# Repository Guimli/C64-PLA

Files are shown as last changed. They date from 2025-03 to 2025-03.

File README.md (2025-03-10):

# Another C64 PLA

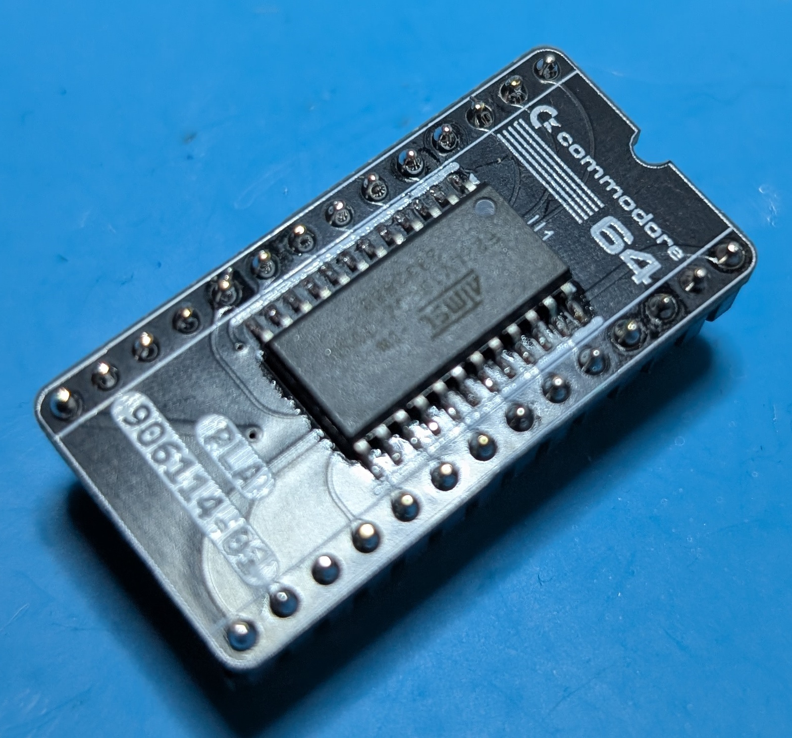
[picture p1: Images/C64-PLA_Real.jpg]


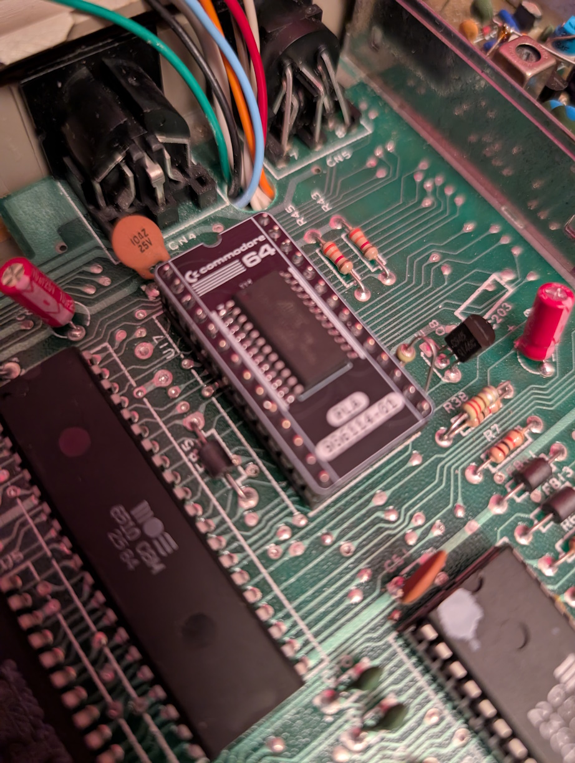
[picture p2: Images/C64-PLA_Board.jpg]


And yes... Another PLA for the C64. There are already too many available. But I thought they were all too big and ugly.
This version uses SOIC format components. This reduces the size of the PCB to that of a standard DIP28. And the components used are still produced, and can therefore be bought from a supplier.
To design this PLA, I used Lubomir Rintel's excellent work: https://github.com/lkundrak/yac64pla

Approximate cost for one C64-PLA (costs can reduced if you build several modules) :

(Be careful to select ATF22LV10s with an access time of 30ns. The Commodore 64 does not appreciate components that are too fast...)

- 2 x ATF22LV10CQZ-30SU  : 8.16 €
- PCB (with Shipping cost) : 23 €
- 2 x 14 pin P2.54 : 4.36 €

Total : 35.52 €

I can sell you this module if you don't want to assemble it yourself. Contact me on guimli@free.fr

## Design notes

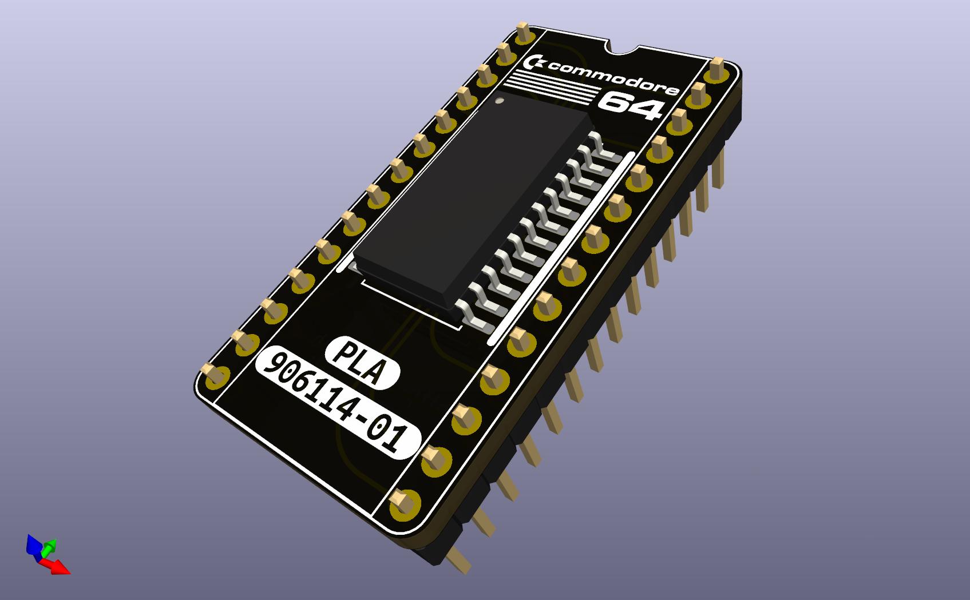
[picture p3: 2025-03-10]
Images/3D.jpg

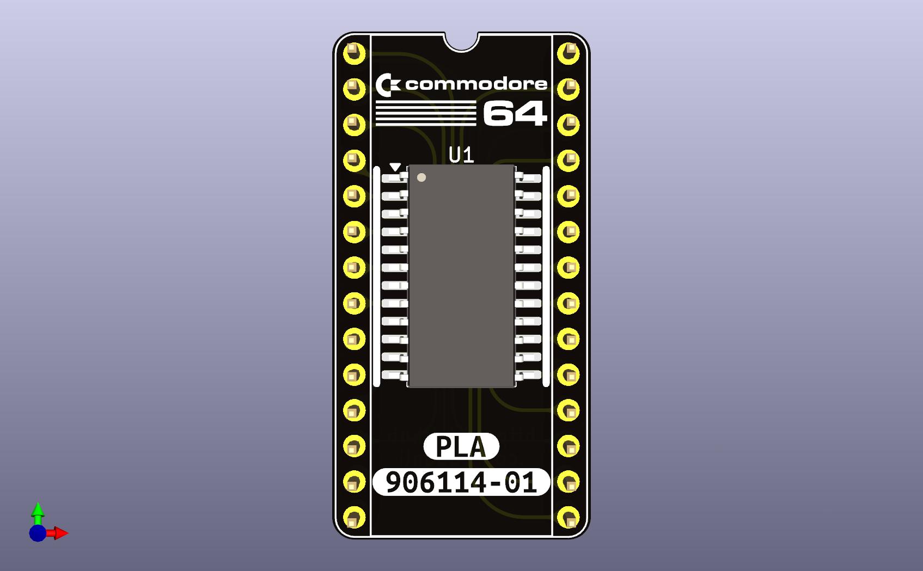
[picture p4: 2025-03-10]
Images/Top.jpg

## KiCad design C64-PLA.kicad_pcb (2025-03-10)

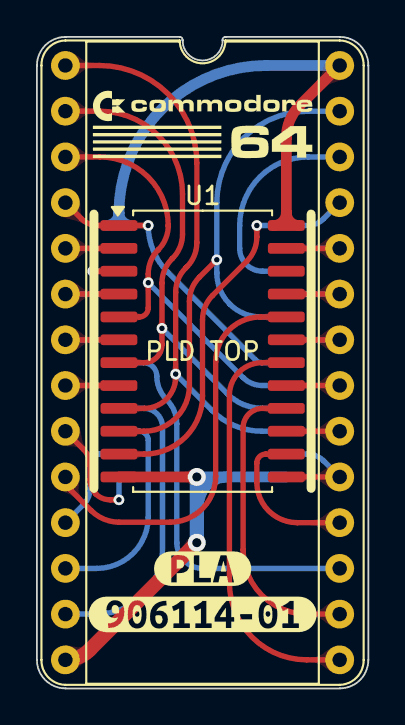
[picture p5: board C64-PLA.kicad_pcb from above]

Board: 2 copper layers, 18.4 x 36.2 mm, 5 parts (1 on the bottom side), 29 nets.

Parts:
U1, U2: ATF22V10C; SOIC-24W_7.5x15.4mm_P1.27mm
U3: C64_PLA; DIP-28_W15.24mm_Socket
kibuzzard-6781C1DF: G***; kibuzzard-6781C1DF
kibuzzard-6781C1F4: G***; kibuzzard-6781C1F4

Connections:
/A12: U1.10 (I9), U2.5 (I4), U3.27 (I8/A12)
/A13: U1.7 (I6), U2.9 (I8), U3.2 (I7/A13)
/A14: U1.5 (I4), U2.8 (I7), U3.3 (I6/A14)
/A15: U1.1 (I0/CLK), U2.7 (I6), U3.4 (I5/A15)
/BA: U2.3 (I2), U3.26 (I9/BA)
/FE: U1.9 (I8), U2.10 (I9), U3.1 (FE/NC)
/GR/~W: U2.16 (I/O14), U3.13 (F4/GR/~W)
/R/~W: U1.23 (I/O21), U2.2 (I1), U3.24 (I11/R/~W)
/TCR: U1.3 (I2), U2.22 (I/O20)
/VA12: U1.15 (I/O13), U3.20 (I15/VA12)
/VA13: U1.17 (I/O15), U3.21 (I14/VA13)
/~AEC: U1.11 (I10), U2.1 (I0/CLK), U3.25 (I10/~AEC)
/~BASIC: U2.18 (I/O16), U3.17 (F1/~BASIC)
/~CASRAM: U1.14 (I/O12), U3.18 (F0/~CASRAM)
/~CAS: U2.13 (I11), U3.9 (I0/~CAS)
/~CHAREN: U1.4 (I3/PD), U2.21 (I/O19), U3.6 (I3/~CHAREN)
/~CHAROM: U1.18 (I/O16), U3.15 (F3/~CHAROM)
/~EXROM: U1.21 (I/O19), U2.4 (I3/PD), U3.23 (I12/~EXROM)
/~GAME: U1.19 (I/O17), U2.6 (I5), U3.22 (I13/~GAME)
/~IRAM: U1.6 (I5), U2.19 (I/O17), U3.7 (I2/~IRAM)
/~I/O: U2.15 (I/O13), U3.12 (F5/~I/O)
/~KERNAL: U1.16 (I/O14), U3.16 (F2/~KERNAL)
/~LORAM: U1.8 (I7), U2.17 (I/O15), U3.8 (I1/~LORAM)
/~OE: U1.13 (I11), U2.11 (I10), U3.19 (~OE)
/~ROMH: U1.20 (I/O18), U3.10 (F7/~ROMH)
/~ROML: U2.14 (I/O12), U3.11 (F6/~ROML)
/~VA14: U1.2 (I1), U3.5 (I4/~VA14)
GND: U1.12 (GND), U2.12 (GND), U3.14 (VSS)
VCC: U1.24 (VCC), U2.24 (VCC), U3.28 (VCC)
